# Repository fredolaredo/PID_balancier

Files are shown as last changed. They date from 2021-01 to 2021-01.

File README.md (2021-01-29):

# PID_balancier

test de mise en oeuvre de PID sur un balancier

## objectif

placer la boule au milieu du balancier en controlant la vitesse du moteur par PID

## composants

limiteur de tension L7805 (5V)

atmega328 en 5V / 16 Mhz (package DIP28)

TMC2208 : driver de moteur BL silencieux 

moteur NEMA17 classique

capteur de distance sharp 2Y1A02

## alimentation

entre 9v et 12v pour driver et uC

## modelisation 3D

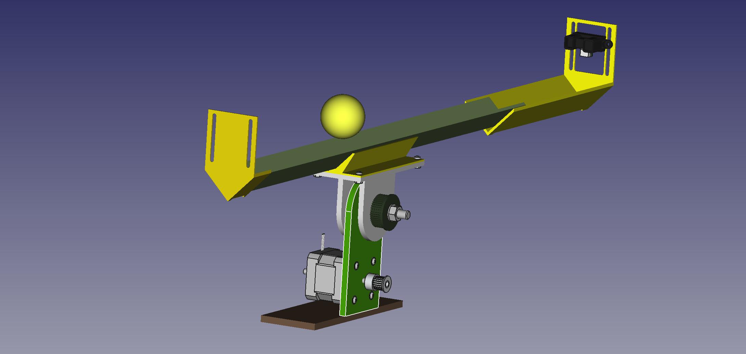
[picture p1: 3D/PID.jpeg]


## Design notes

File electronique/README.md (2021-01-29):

fichiers au format kicad

PID : fichiers qui ont servi a faire le premier proto

PID_CMS : tentative de gravure de PCB avec composants de surface (en cours)

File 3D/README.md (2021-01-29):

modelisation au format FreeCAD 

2021/01/20 : importation sur version RealThunder qui a cassé certaines contraintes : la flemme de tout refaire

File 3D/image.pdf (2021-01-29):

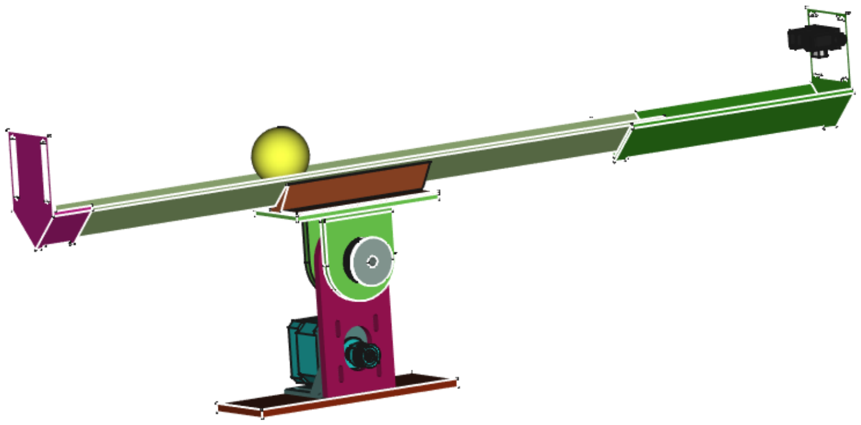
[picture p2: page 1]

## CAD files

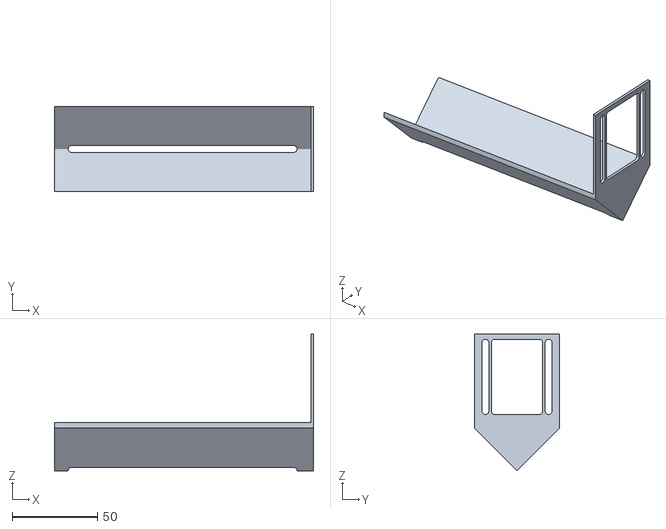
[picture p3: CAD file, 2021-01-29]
3D/support_G2Y0.stl
151.6 x 50.0 x 80.0

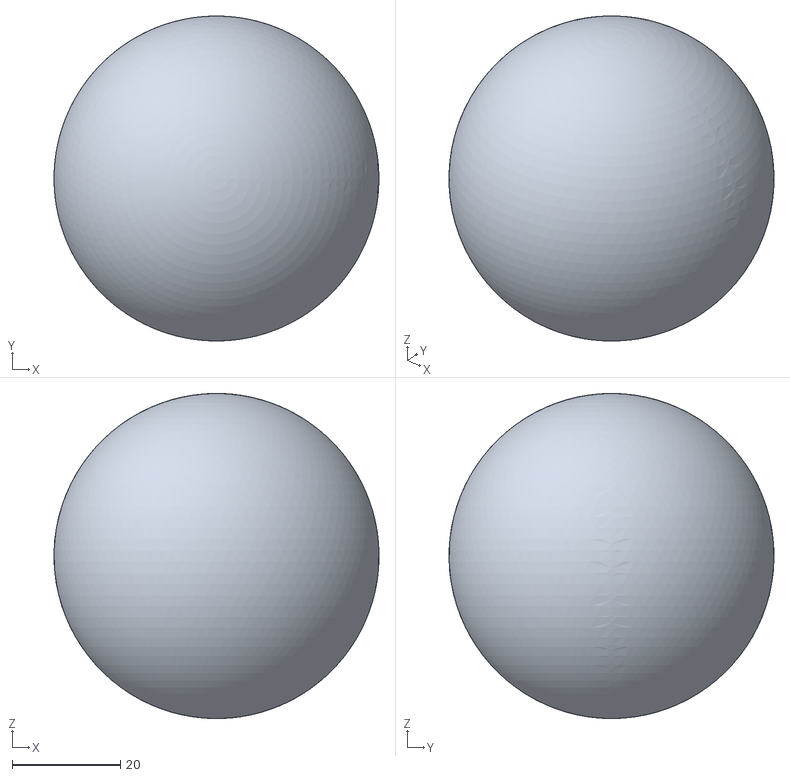
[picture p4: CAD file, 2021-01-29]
3D/mobile.stl
60.0 x 60.0 x 60.0

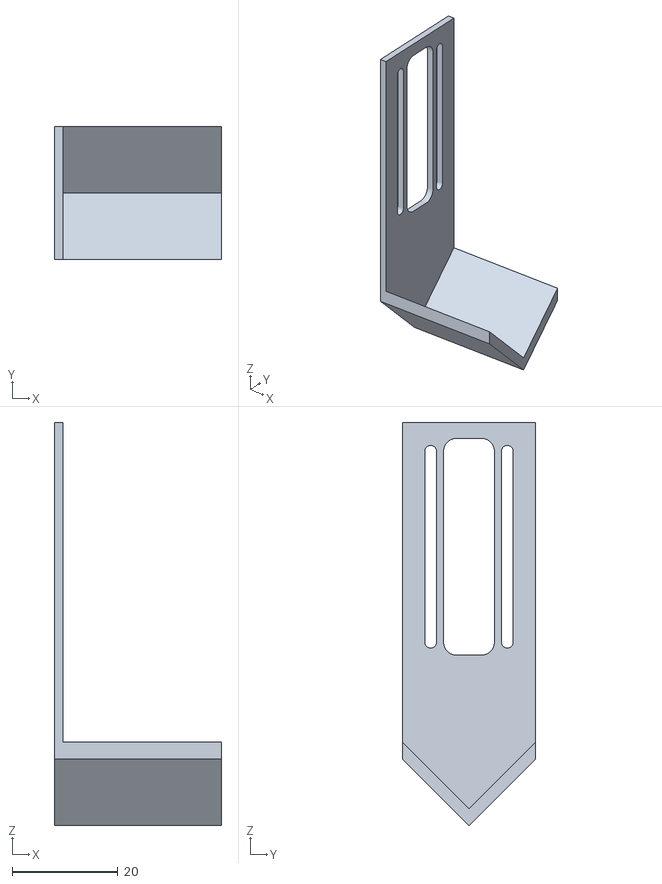
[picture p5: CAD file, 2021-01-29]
3D/support_TOF10120_2.stl
31.6 x 25.2 x 76.2

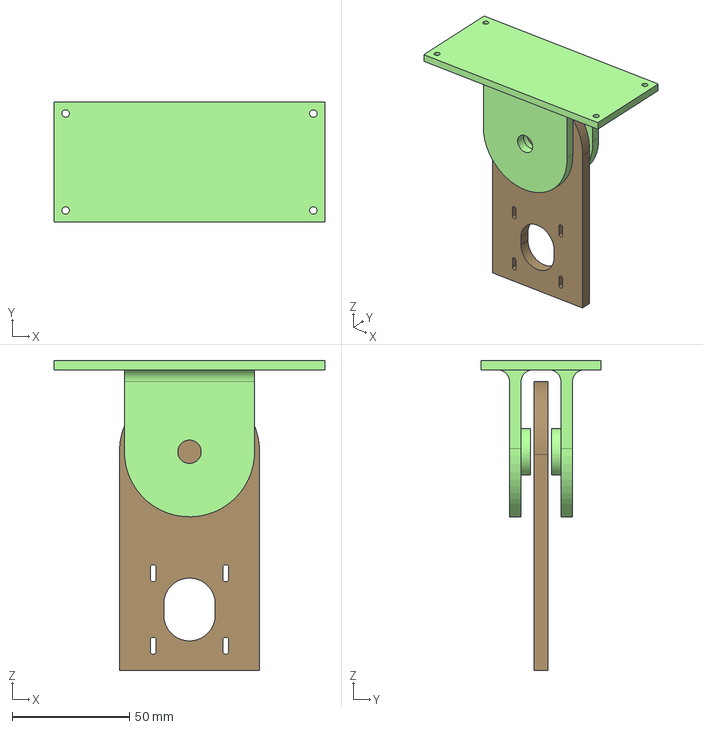
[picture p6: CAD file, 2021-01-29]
3D/pid.FCStd
115.8 x 51.4 x 132.5 mm
Pied
Support

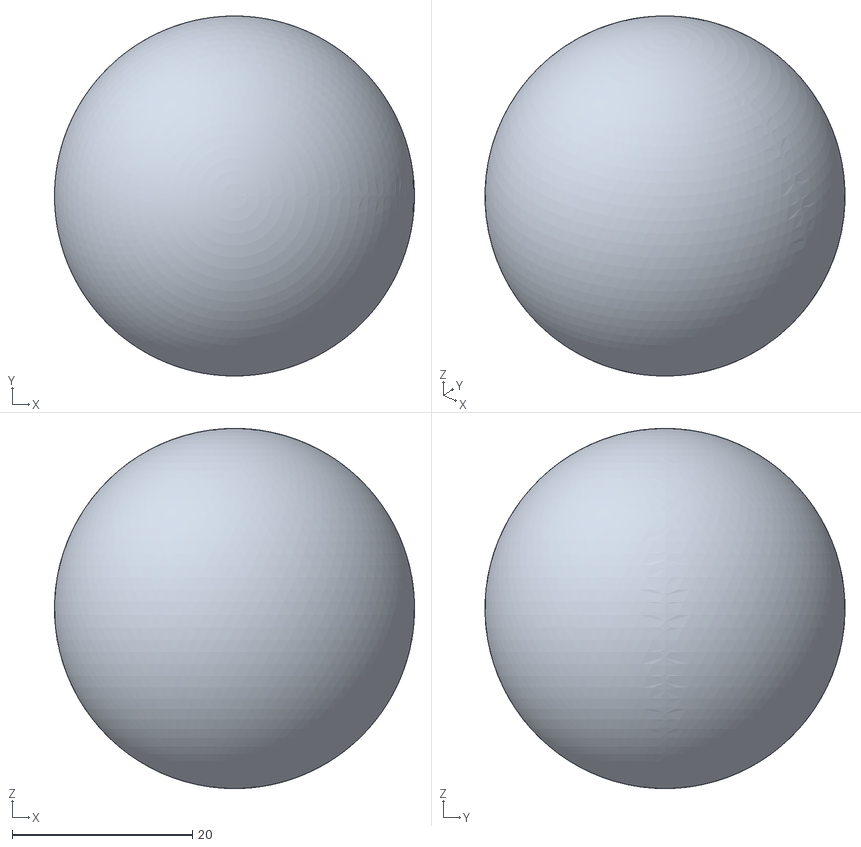
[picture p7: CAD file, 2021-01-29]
3D/boule.stl
40.0 x 40.0 x 40.0

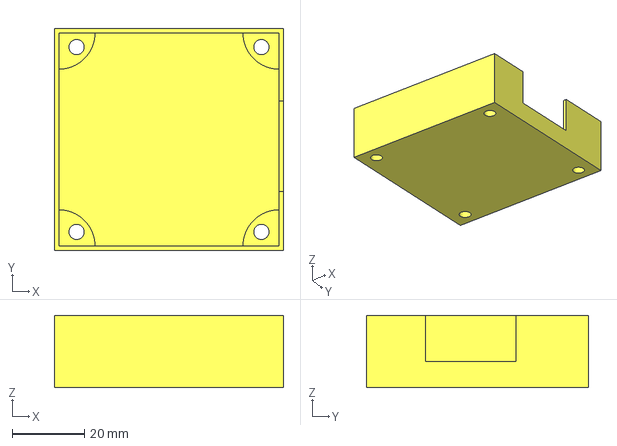
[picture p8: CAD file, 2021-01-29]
3D/boitier.FCStd
63.2 x 61.2 x 20.0 mm

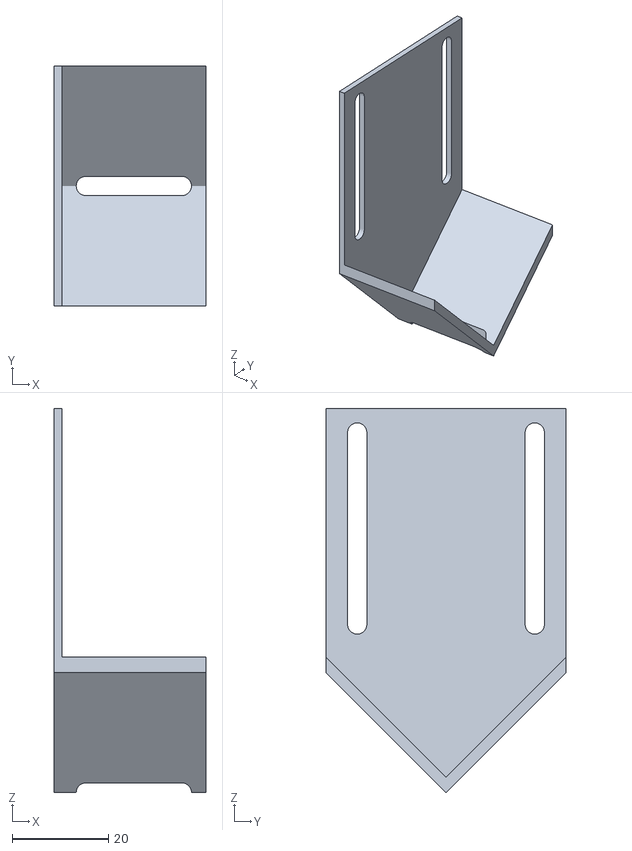
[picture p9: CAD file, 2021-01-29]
3D/contre_balancier.stl
31.6 x 50.0 x 80.0

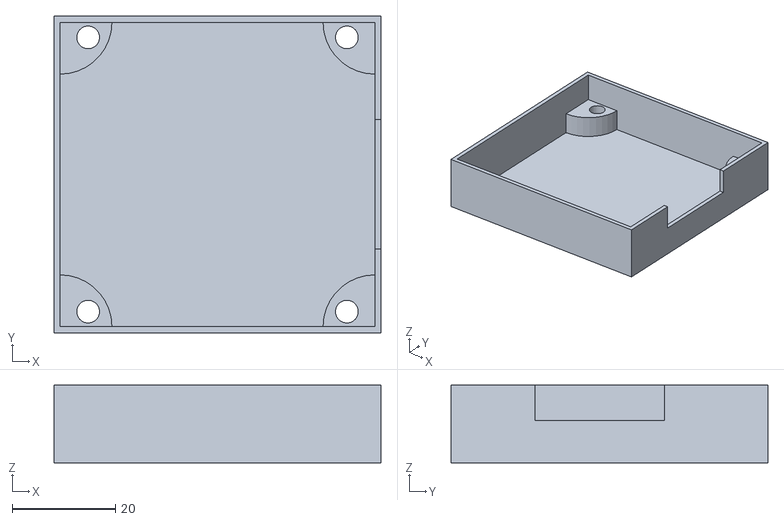
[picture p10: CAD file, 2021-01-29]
3D/boite.stl
63.2 x 61.2 x 15.0

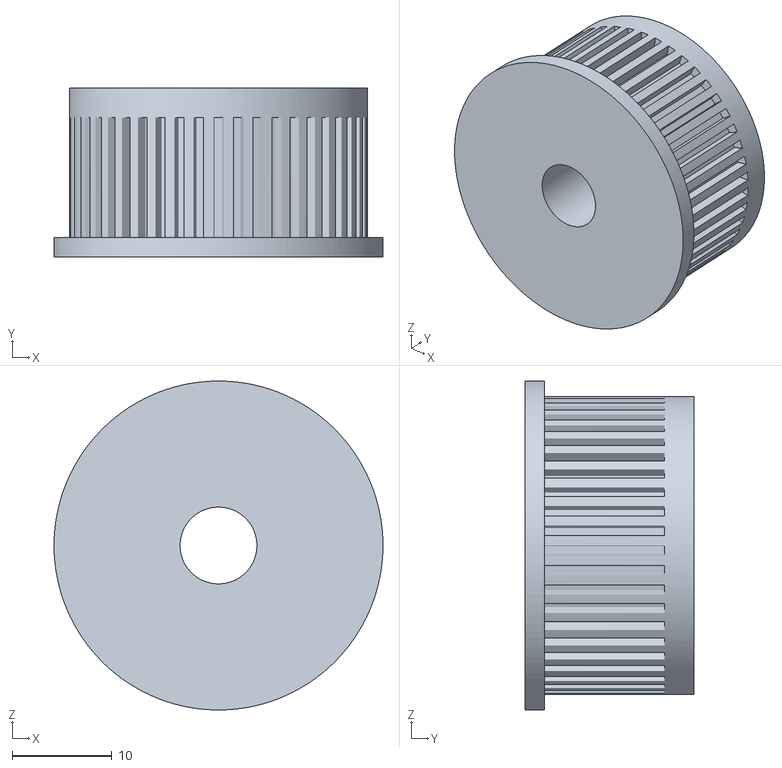
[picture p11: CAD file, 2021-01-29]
3D/axe_support.stl
33.0 x 17.0 x 33.0

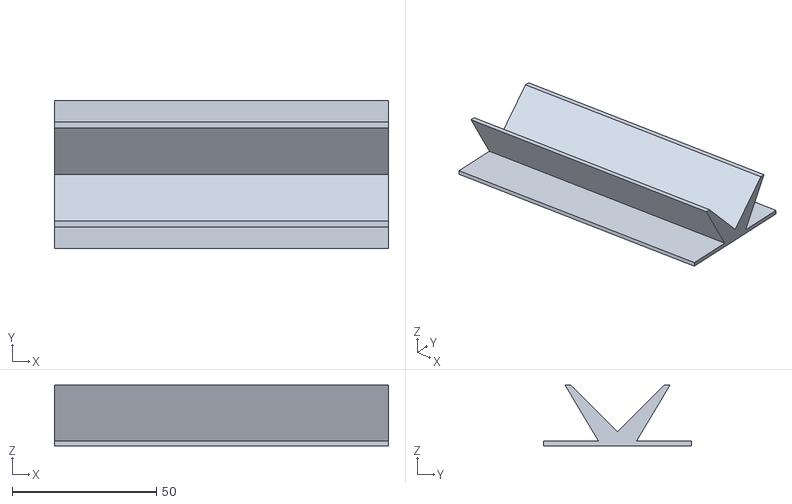
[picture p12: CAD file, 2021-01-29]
3D/rail_leger.stl
115.8 x 51.4 x 21.0

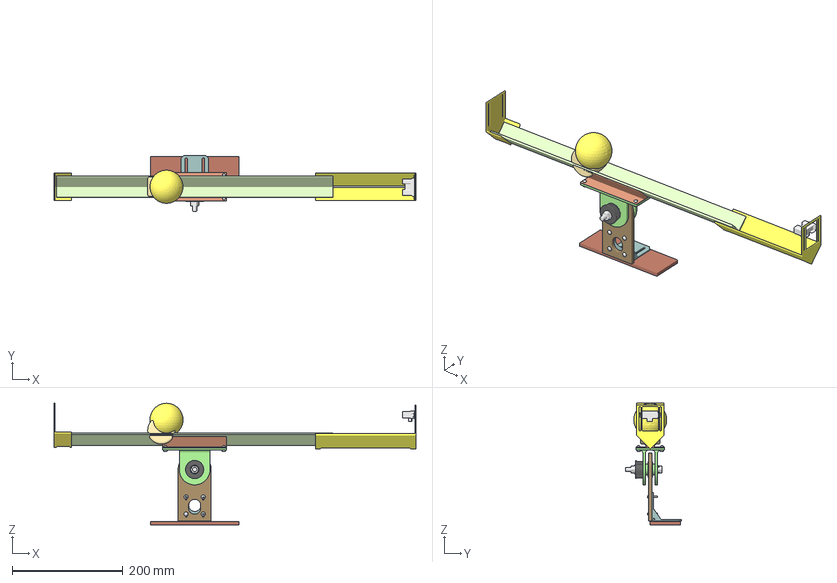
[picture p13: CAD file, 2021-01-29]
3D/pid 20210102_193333.FCStd
655.2 x 100.7 x 220.0 mm
Pied
Bearing
Axe_support
Support
Mobile
Boule
Support Rail leger
Support_G2Y0
Rail leger
Contre_poids_balancier
support_pied
GP2Y0A003
Visserie
clamp stepmotor nema 17

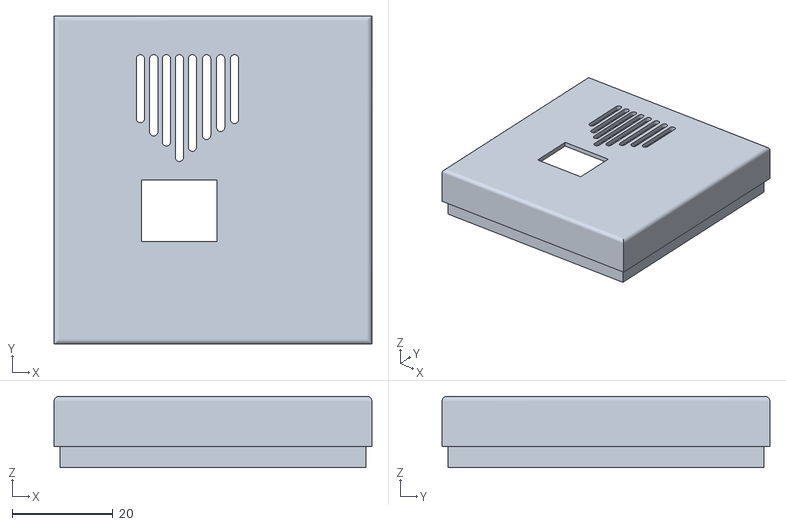
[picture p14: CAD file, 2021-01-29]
3D/couvercle.stl
63.2 x 65.2 x 14.2

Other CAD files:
3D/mobile.amf

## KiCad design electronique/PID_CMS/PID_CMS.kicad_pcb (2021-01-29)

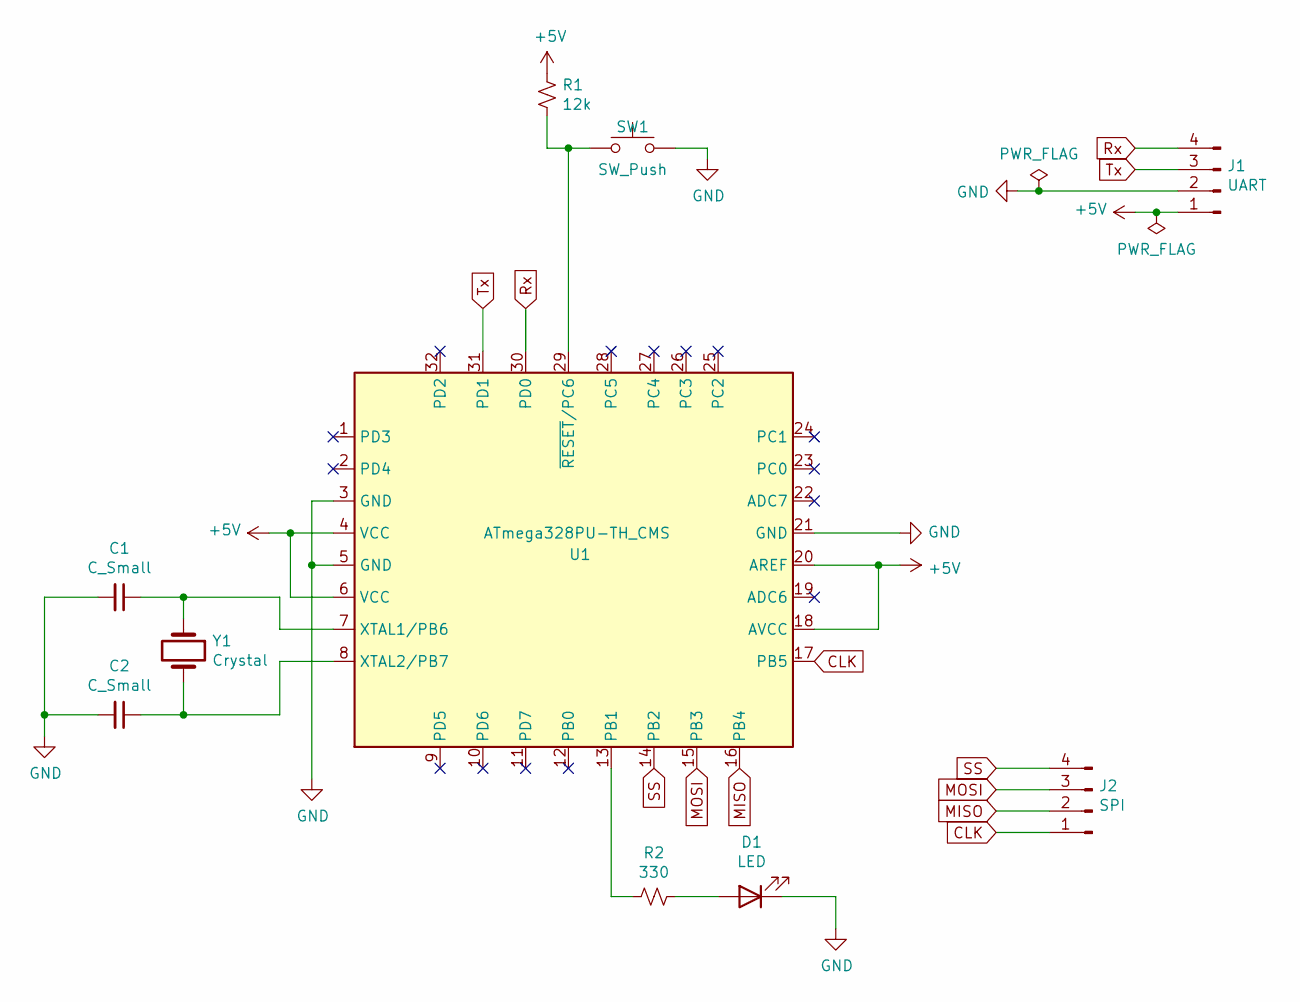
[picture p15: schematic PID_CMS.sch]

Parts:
C1, C2: C_Small; C_Disc_D4.3mm_W1.9mm_P5.00mm
D1: LED; LED_0805_2012Metric
J1: UART; PinHeader_1x04_P2.54mm_Horizontal
J2: SPI; PinHeader_1x04_P2.54mm_Horizontal
R1: 12k; R_1206_3216Metric
R2: 330; R_1206_3216Metric
SW1: SW_Push; SW_Push_SPST_NO_Alps_SKRK
U1: ATmega328PU-TH_CMS; TQFP-32_7x7mm_P0.8mm
Y1: Crystal; Resonator-2Pin_W10.0mm_H5.0mm

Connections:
+5V: J1.1, R1.1, U1.4 (VCC), U1.6 (VCC), U1.18 (AVCC), U1.20 (AREF)
CLK: J2.1, U1.17 (PB5)
GND: C1.2, C2.2, D1.1 (K), J1.2, SW1.2, U1.3 (GND), U1.5 (GND), U1.21 (GND)
MISO: J2.2, U1.16 (PB4)
MOSI: J2.3, U1.15 (PB3)
unnamed: C1.1, U1.7 (XTAL1/PB6), Y1.1
unnamed: C2.1, U1.8 (XTAL2/PB7), Y1.2
unnamed: D1.2 (A), R2.1
unnamed: R1.2, SW1.1, U1.29 (~RESET~/PC6)
unnamed: R2.2, U1.13 (PB1)
Rx: J1.4, U1.30 (PD0)
SS: J2.4, U1.14 (PB2)
Tx: J1.3, U1.31 (PD1)

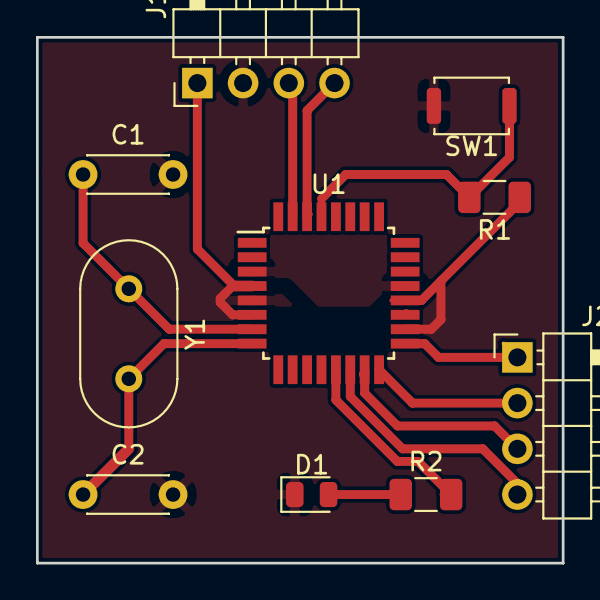
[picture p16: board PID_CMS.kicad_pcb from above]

Board: 2 copper layers, 29.2 x 29.2 mm, 10 parts (0 on the bottom side), 13 nets.

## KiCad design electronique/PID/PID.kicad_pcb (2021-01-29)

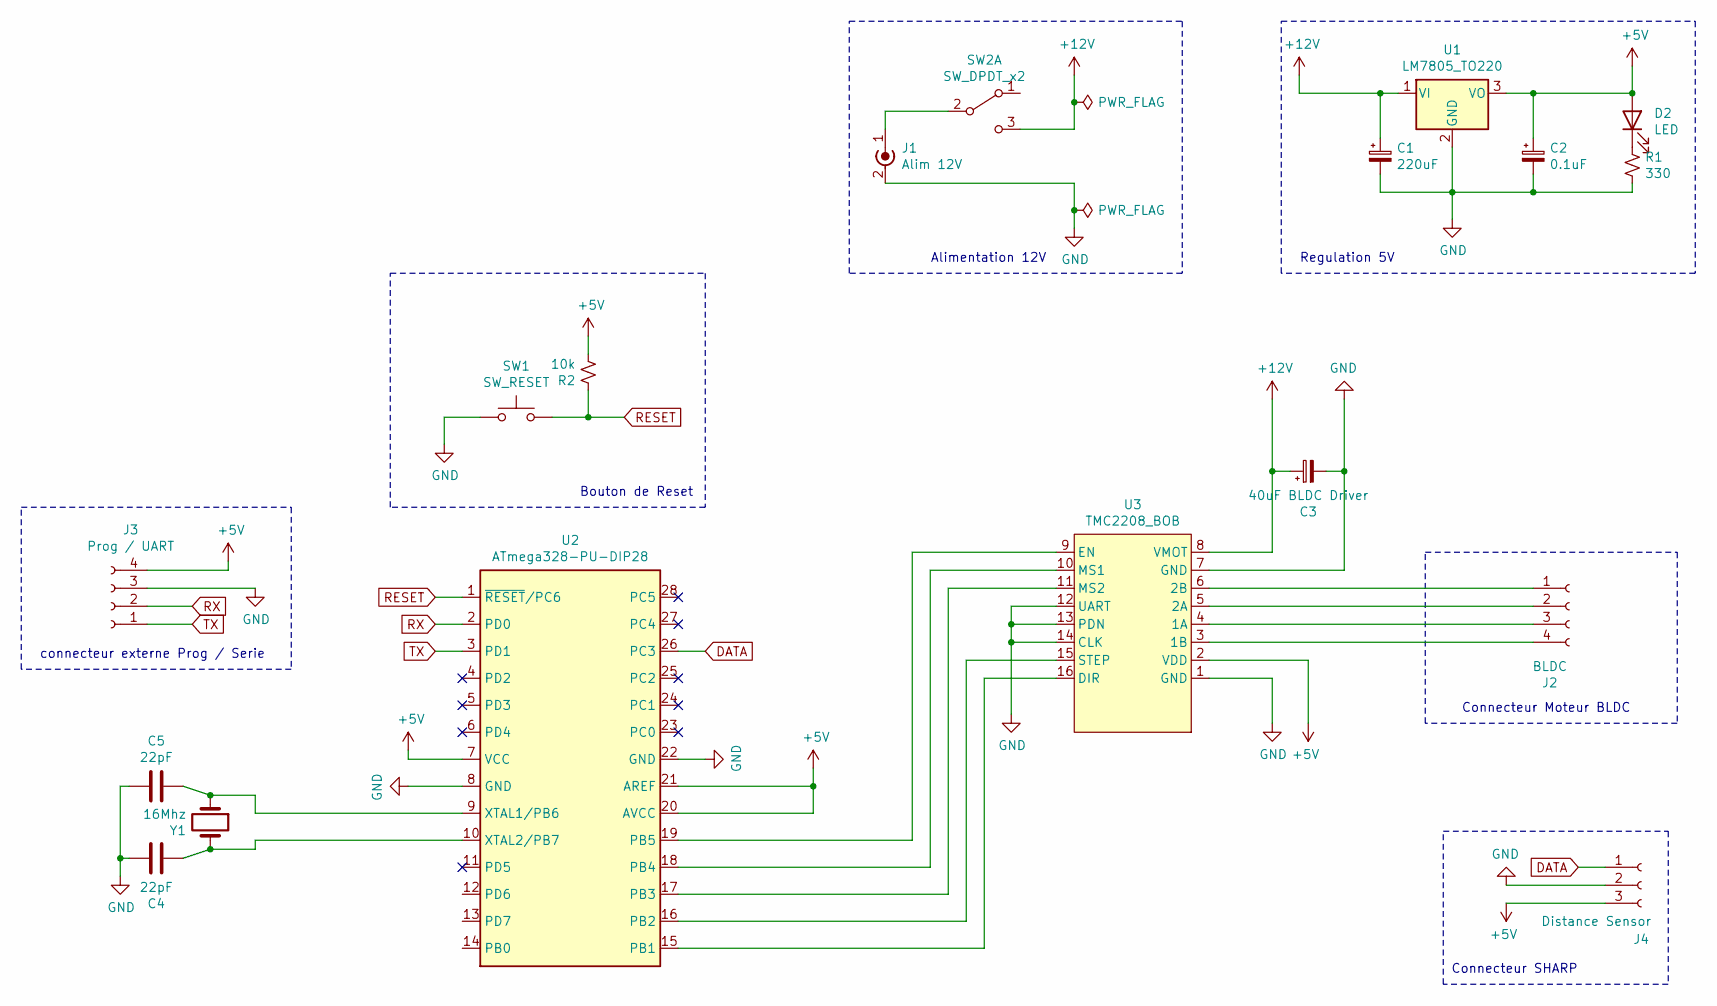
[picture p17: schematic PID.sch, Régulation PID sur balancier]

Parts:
C1: 220uF; CP_Radial_D5.0mm_P2.50mm
C2: 0.1uF; CP_Radial_D5.0mm_P2.50mm
C3: 40uF BLDC Driver; CP_Radial_D8.0mm_P3.50mm
C4, C5: 22pF; C_Disc_D3.0mm_W1.6mm_P2.50mm
D2: LED; LED_D5.0mm
J1: Alim 12V; BarrelJack_Horizontal
J2: BLDC; PinHeader_1x04_P2.54mm_Vertical
J3: Prog / UART; PinHeader_1x04_P2.54mm_Vertical
J4: Distance Sensor; PinHeader_1x03_P2.54mm_Vertical
R1: 330; R_Axial_DIN0204_L3.6mm_D1.6mm_P7.62mm_Horizontal
R2: 10k; R_Axial_DIN0204_L3.6mm_D1.6mm_P7.62mm_Horizontal
SW1: SW_RESET; SW_PUSH_6mm
SW2: SW_DPDT_x2; PinHeader_1x03_P2.54mm_Vertical
U1: LM7805_TO220; TO-220-3_Vertical
U2: ATmega328-PU-DIP28; DIP-28_W7.62mm
U3: TMC2208_BOB
Y1: 16Mhz; Resonator-2Pin_W8.0mm_H3.5mm

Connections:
+5V: C2.1, D2.2 (A), J3.4, J4.3, R2.2, U1.3 (VO), U2.7 (VCC), U2.20 (AVCC), U2.21 (AREF), U3.2 (VDD)
+12V: C1.1, C3.1, SW2.3 (C), U1.1 (VI), U3.8 (VMOT)
DATA: J4.1, U2.26 (PC3)
GND: C1.2, C2.2, C3.2, C4.1, C5.2, J1.2 (Ext), J3.3, J4.2, R1.2, SW1.1, U1.2 (GND), U2.8 (GND), U2.22 (GND), U3.1 (GND), U3.7 (GND), U3.12 (UART), U3.13 (PDN), U3.14 (CLK)
unnamed: C4.2, U2.10 (XTAL2/PB7), Y1.2
unnamed: C5.1, U2.9 (XTAL1/PB6), Y1.1
unnamed: D2.1 (K), R1.1
unnamed: J1.1 (In), SW2.2 (B)
unnamed: J2.1, U3.6 (2B)
unnamed: J2.2, U3.5 (2A)
unnamed: J2.3, U3.4 (1A)
unnamed: J2.4, U3.3 (1B)
unnamed: U2.15 (PB1), U3.16 (DIR)
unnamed: U2.16 (PB2), U3.15 (STEP)
unnamed: U2.17 (PB3), U3.11 (MS2)
unnamed: U2.18 (PB4), U3.10 (MS1)
unnamed: U2.19 (PB5), U3.9 (EN)
RESET: R2.1, SW1.2, U2.1 (~RESET~/PC6)
RX: J3.2, U2.2 (PD0)
TX: J3.1, U2.3 (PD1)

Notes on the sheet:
connecteur externe Prog / Serie
Alimentation 12V
Connecteur Moteur BLDC
Regulation 5V
Bouton de Reset
Connecteur SHARP

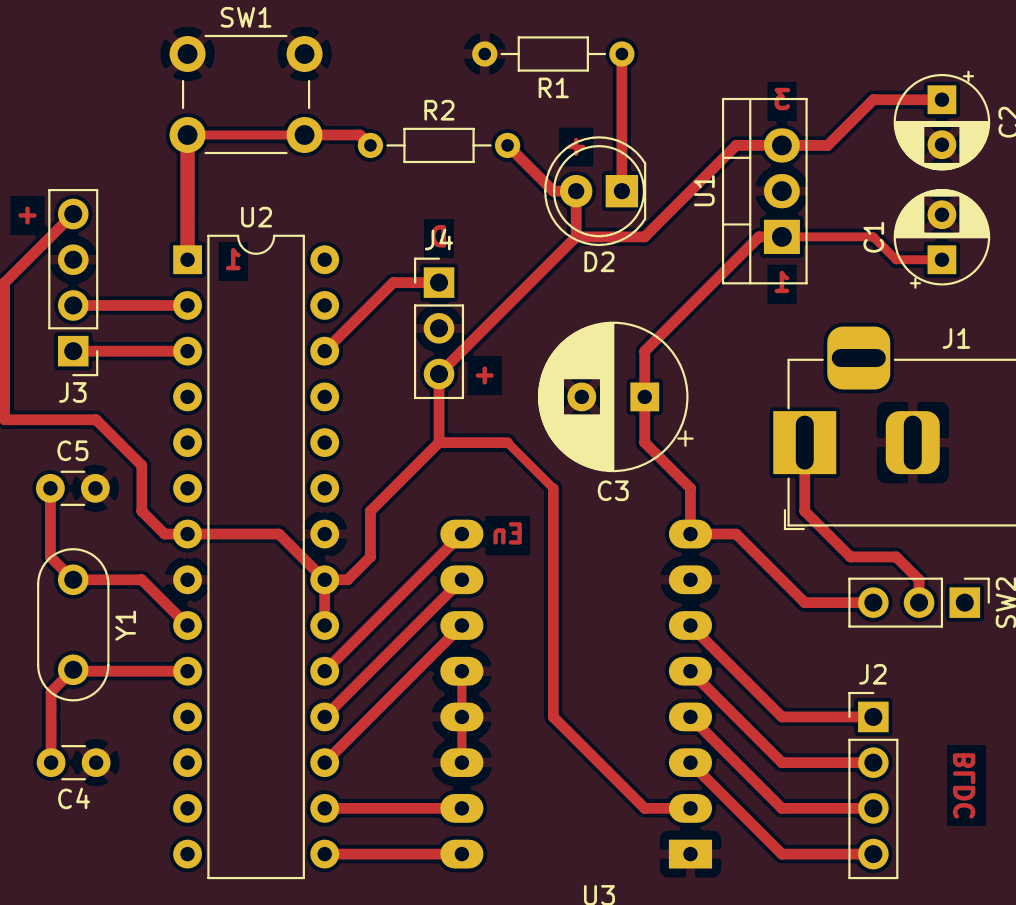
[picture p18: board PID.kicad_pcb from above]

Board: 2 copper layers, 18 parts (0 on the bottom side), 20 nets.

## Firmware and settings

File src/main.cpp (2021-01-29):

#include <Arduino.h>

/////////////////////////////////////////////////////////////
// GP2YOA02 distance sensor
/////////////////////////////////////////////////////////////
#define DISTANCE_PIN      A3

unsigned int readDistance(int nb = 1) {
  unsigned int val = 0;
  for (int i=0 ; i<nb ;i++) {
    val += analogRead(DISTANCE_PIN);
    delayMicroseconds(10);
  }
  return val / nb; // / nb;
}

/////////////////////////////////////////////////////////////
// Stepper  
/////////////////////////////////////////////////////////////
#include <AccelStepper.h>

// CNC Shield
// pinout diagram
#define MOTOR_ENABLE    13          // PB5  13 ou  5
#define X_AXIS_STEP     10          //
#define X_AXIS_DIR      9           // PB1

#define MS1             12          // PB4
#define MS2             11          // PB4

#define FULL_STEPS_PER_ROTATION     200.0
#define MICRO_STEPPING              16
#define STEPS_PER_ROTATION          FULL_STEPS_PER_ROTATION * MICRO_STEPPING  /// 16 * 200 = 3200 ---- 32 x 200 = 6400
//int delay_steps = 100;
bool clockwise = true;

// Define a stepper and the pins it will use
AccelStepper stepper(AccelStepper::DRIVER, X_AXIS_STEP, X_AXIS_DIR);

/////////////////////////////////////////////////////////////
// PID
/////////////////////////////////////////////////////////////
const float Kp = 0.20;     //0.10
const float Kd = 1.50;     //1.00; 
const float Ki = 0.50;     //0.01;

int target = 300;

unsigned long last_T, last_millis = millis();
volatile float sum_error, delta_error, delta_T, output = 0;
volatile float P,I,D = 0;
volatile int input, last_input = target;
volatile int error, last_error = 0;

float calcul_pid() {
  delta_T = (millis() - last_T) / 1000.0F ;
  last_T = millis();
  error = target - input;
  sum_error += (error * delta_T);
  delta_error = (error - last_error) / delta_T ;
  P = (Kp * error);
  I = (Ki * sum_error);
  D = (Kd * delta_error);
  float out = P + I + D ; 
  last_error = error;
  return out;
}

/////////////////////////////////////////////////////////////
// AVR Timer
/////////////////////////////////////////////////////////////

ISR(TIMER1_COMPA_vect) {
  input = readDistance(5);
  output = calcul_pid();
  stepper.setSpeed(output);
  TCNT1 = 0;
}

void initTimer1() {
  cli();
  TCCR1A = 0;                       // Timer/Counter1 Control Register A (COM1A1 COM1A0 COM1B1 COM1B0 – – WGM11 WGM10)
  TCCR1B &= ~(1 << CS12);           // prescaler 8  = B010
  TCCR1B |=  (1 << CS11);           //           64 = B011
  TCCR1B |=  (1 << CS10);
  OCR1A  =  (F_CPU / 64) * 0.005;   // (16000000 / 64) = 250 000 (counts/s)   => compare on 0.020s =  5 000
                                    // (16000000 / 8 ) = 2 000 000 (counts/s) => compare on 0.005s = 10 000
  TIMSK1 |= (1 << OCIE1A);          // Output Compare A
  TCNT1 = 0;                        // set start counter to 0
  sei();
}


/////////////////////////////////////////////////////////////
// Setup
/////////////////////////////////////////////////////////////

void setup() {
  Serial.begin(115200);
  while(!Serial);
  
  stepper.setPinsInverted(true,false,true);    // TMC2208
  // stepper.setPinsInverted(false,true,true); // DRV8825
  stepper.setEnablePin(MOTOR_ENABLE);
  stepper.enableOutputs();
  stepper.setMaxSpeed(5000.0);
  stepper.setAcceleration(5000.0);

  // set microstepping to 16
  pinMode (MS1, OUTPUT);
  digitalWrite(MS1, HIGH);
  pinMode (MS2, OUTPUT);
  digitalWrite(MS2, HIGH);

  Serial.println("error P I D");

  // target = readDistance(100);

  initTimer1();

}

/////////////////////////////////////////////////////////////
// Loop
/////////////////////////////////////////////////////////////

void loop()
{

  // if (millis() - last_millis > 200) {
  //   Serial.print(error); Serial.print("\t");
  //   Serial.print(P); Serial.print("\t");
  //   Serial.print(I); Serial.print("\t");
  //   Serial.print(D / 100); Serial.print("\t");
  //   Serial.println();
  //   last_millis = millis();
  // }
  
  stepper.runSpeed();
  
}
